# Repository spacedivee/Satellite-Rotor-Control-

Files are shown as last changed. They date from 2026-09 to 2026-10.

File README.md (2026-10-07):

iso all2

## *$FOR THE STARDANCE REVIEWERS$*
- In case you haven't read it through my comments already , my BOM.csv is irrelevant if you guys can **ship me a HackPad kit** +(the PCB grant). I need the exact same components as the components in the kit, so sending me my grant isn't necessary (Either way my BOM contains the same components bought individually (which just costs more than your bulk), so its a win-win for both of us if you ship a **HackPad kit**. Note: I would submit this project as a hackpad, but previous reviewers have been agaisnt that. Thank you for your understanding.

## Custom Satellite Control Interface
A custom PCB-based controller designed as a physical interface for controlling software on a computer. It can be used as a general-purpose control pad, with a focus on eventually controlling a **satellite antenna rotator** (which is another project I am building).

## Components and building materials.
* 4× MX-style buttons
* EC11E rotary encoder with push button
* 0.91" OLED display
* Seeed XIAO RP2040
* Custom KiCad PCB
* 3D-printed Onshape enclosure

## PCB+Circuit

pcb ctrl circuit1

## How It Works
The XIAO RP2040 reads the buttons and rotary encoder and sends their inputs to software running on a computer. The OLED provides feedback to the user. In my case, the OLED will display Azimuth and Elevation as they are being changed so the antenna adjustmenet can be simplified. The Encoder will be used to manually adjust the increment of the motors, such that each press will be greater or smaller, depending on the input. 
All of the information will then be sent to the XIAO, which will then sent it to my computer as keystroke data (my current method), which my antenna rotator software will then acknowledge. 

## Tools (if you were interested..?)

* **KiCad** — PCB design
* **Onshape** — enclosure design
* **Arduino/C++** — programming
* **JLCPCB** — PCB manufacturing

## Firmware
For the record, this is the only aspect of my project that was completely made by AI. The current firmware is a placeholder and I plan on writing it myself once I have built the board. I believe this is a better way
of doing things since I get to actively troubleshoot issues. I hope yall feel the same way about this ❤️.

## Bill of Materials

| Item | Component Name | Qty | Price (USD) | Notes |
| :---: | :--- | :---: | :---: | :--- |
| 1 | [Seeed XIAO RP2040](https://www.amazon.ca/dp/B0FB5BS2NX?psc=1&ref_=cm_sw_r_cp_ud_ct_R7M1Z3YGXBJXF9ZXZQDJ_10) | 1 | $19.32 | Main microcontroller |
| 2 | [1N4148 through-hole diodes](https://www.amazon.ca/dp/B099PPQ7YN?psc=1&ref_=cm_sw_r_cp_ud_ct_R7M1Z3YGXBJXF9ZXZQDJ_9) | 4 | $1.50 | Button/switch matrix |
| 3 | [MX-style switches](https://www.amazon.ca/dp/B0HJFQYWR2?psc=1&ref_=cm_sw_r_cp_ud_ct_R7M1Z3YGXBJXF9ZXZQDJ_8) | 4 | $5.99 | Main input buttons |
| 4 | [EC11E rotary encoder with switch](https://www.amazon.ca/dp/B0GJS5SQPF?psc=1&ref_=cm_sw_r_cp_ud_ct_R7M1Z3YGXBJXF9ZXZQDJ_7) | 1 | $8.79 | - |
| 5 | [0.91 inch OLED display](https://www.amazon.ca/dp/B0GWPY5LMY?psc=1&ref_=cm_sw_r_cp_ud_ct_R7M1Z3YGXBJXF9ZXZQDJ_5) | 1 | $6.67 | GND-VCC-SCL-SDA pin order |
| 6 | [White blank DSA keycaps](https://www.amazon.ca/dp/B0BWDR7LQQ?psc=1&ref_=cm_sw_r_cp_ud_ct_R7M1Z3YGXBJXF9ZXZQDJ_4) | 4 | $12.50 | Keycaps for MX switches |
| 7 | [M3x16mm screws](https://www.amazon.ca/dp/B0DDNJXLF3?psc=1&ref_=cm_sw_r_cp_ud_ct_R7M1Z3YGXBJXF9ZXZQDJ_3) | 4 | $8.59 | Case assembly |
| 8 | [M3x5mmx4mm heat-set inserts](https://www.amazon.ca/dp/B0BYVLPG4R?psc=1&ref_=cm_sw_r_cp_ud_ct_R7M1Z3YGXBJXF9ZXZQDJ_1) | 4 | $8.49 | Case assembly |
| 9 | $10 JLCPCB credit | 1 | $10.00 | PCB manufacturing |
| 10 | LED | 1 | $0.00 | - supplied by me |
| 11 | Resistor | 1 | $0.00 | - supplied by me |
| | **Total Estimated Cost:** | | **$81.85** | |

> **Note:** If you have an existing hackpad kit available, I would happily accept that as an alternative. It may be more cost-effective and prevents acquiring unnecessary duplicate components.

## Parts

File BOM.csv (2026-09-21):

Item Name | Qty | Price (total) (USD) | Item link | Notes
Seeed XIAO RP2040 | 1 | $19.32 | https://www.amazon.ca/dp/B0FB5BS2NX?psc=1&ref_=cm_sw_r_cp_ud_ct_R7M1Z3YGXBJXF9ZXZQDJ_10 | Main microcontroller
1N4148 through-hole diodes | 4 | $1.50 | https://www.amazon.ca/dp/B099PPQ7YN?psc=1&ref_=cm_sw_r_cp_ud_ct_R7M1Z3YGXBJXF9ZXZQDJ_9 | Button/switch matrix
MX-style switches | 4 | $5.99 | https://www.amazon.ca/dp/B0HJFQYWR2?psc=1&ref_=cm_sw_r_cp_ud_ct_R7M1Z3YGXBJXF9ZXZQDJ_8 | Main input buttons
EC11E rotary encoder with switch | 1 | $8.79 | https://www.amazon.ca/dp/B0GJS5SQPF?psc=1&ref_=cm_sw_r_cp_ud_ct_R7M1Z3YGXBJXF9ZXZQDJ_7 | -
0.91 inch OLED display | 1 | $6.67 | https://www.amazon.ca/dp/B0GWPY5LMY?psc=1&ref_=cm_sw_r_cp_ud_ct_R7M1Z3YGXBJXF9ZXZQDJ_5 | GND-VCC-SCL-SDA pin order
White blank DSA keycaps | 4 | $12.50 | https://www.amazon.ca/dp/B0BWDR7LQQ?psc=1&ref_=cm_sw_r_cp_ud_ct_R7M1Z3YGXBJXF9ZXZQDJ_4 | Keycaps for MX switches
M3x16mm screws | 4 | $8.59 | https://www.amazon.ca/dp/B0DDNJXLF3?psc=1&ref_=cm_sw_r_cp_ud_ct_R7M1Z3YGXBJXF9ZXZQDJ_3 | Case assembly
M3x5mmx4mm heat-set inserts | 4 | $8.49 | https://www.amazon.ca/dp/B0BYVLPG4R?psc=1&ref_=cm_sw_r_cp_ud_ct_R7M1Z3YGXBJXF9ZXZQDJ_1 | Case assembly
$10 JLCPCB credit | 1 | $10.00 |  | PCB manufacturing
LED | 1 | $0.00 |  | - supplied by me
Resistor | 1 | $0.00 |  | - supplied by me
Total Price (USD): | $81.85
However, if you guys have a hackpad kit laying around, i will gladly take that instead of all of this list of materials, since its cheaper for you and I dont require all of these extra parts for my project.

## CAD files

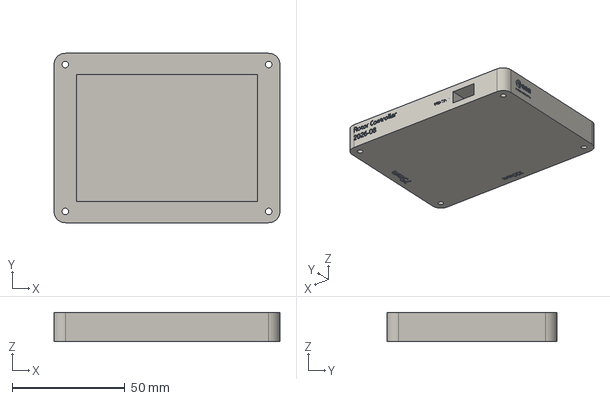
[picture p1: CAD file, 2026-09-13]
CaseFiles/Case(step).step
100.0 x 75.0 x 13.0 mm

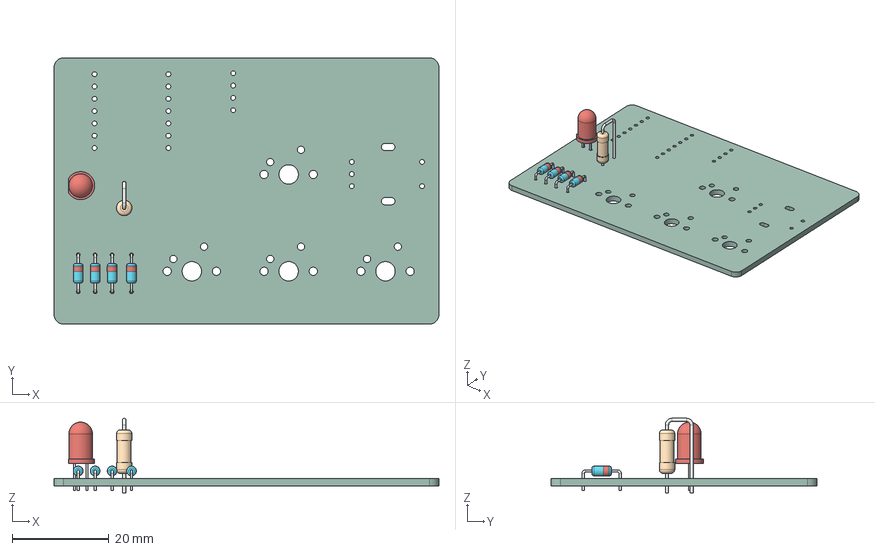
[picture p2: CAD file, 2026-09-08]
PCB/KiCad Files/yo/yo.step
79.5 x 55.0 x 15.4 mm
D_DO-35_SOD27_P7.62mm_Horizontal x 4
LED_D5.0mm
R_Axial_DIN0309_L90mm_D32mm_P508mm_Vertical
yo-37B0_PCB

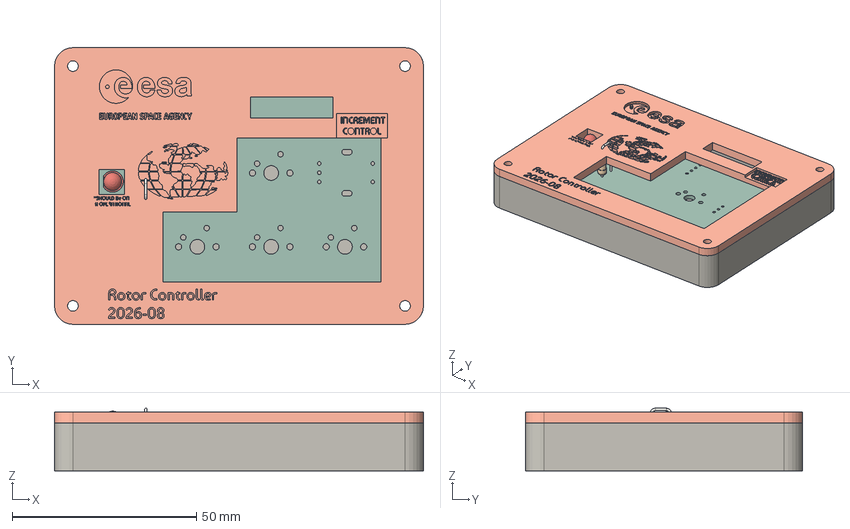
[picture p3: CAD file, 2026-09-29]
SatContrl_electronics+CAD.step
100.0 x 75.0 x 17.0 mm
main:1__Body5
main:1__Body16
main:1__Body4
main:1__Body10
main:1__Body13
main:1__Body6
main:1__Body12
main:1__Body1
main:1__Body9
smd_button v3:1__Body1
main:1__Body14
main:1__Body3
main:1__Body7
main:1__Body11
DOUT:1__Body1
VDD:1__Body1
VSS:1__Body1
DIN:1__Body1
Shell:1__Body1
main:1__Body15
main:1__Body8
type-c v2:1__Body2
type-c v2:1__Body6
type-c v2:1__Body4
type-c v2:1__Body20
type-c v2:1__Body5
type-c v2:1__Body15
type-c v2:1__Body17
type-c v2:1__Body3
type-c v2:1__Body11
type-c v2:1__Body1
type-c v2:1__Body23
type-c v2:1__Body7
type-c v2:1__Body12
type-c v2:1__Body14
type-c v2:1__Body13
type-c v2:1__Body16
type-c v2:1__Body21
type-c v2:1__Body8
type-c v2:1__Body22
type-c v2:1__Body18
type-c v2:1__Body24
type-c v2:1__Body9
type-c v2:1__Body19
type-c v2:1__Body10
smd_button v3(Mirror):1__Body2
main:1__Body17
R_Axial_DIN0309_L90mm_D32mm_P508mm_Vertical
D_DO-35_SOD27_P7.62mm_Horizontal x 8
LED_D5.0mm
yo-37B0_PCB

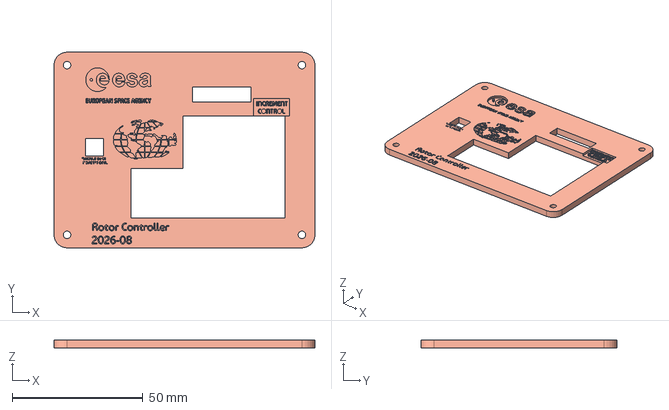
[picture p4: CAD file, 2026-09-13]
CaseFiles/Lid(step).step
100.0 x 75.0 x 3.00 mm

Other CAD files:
CaseFiles/CASELID.stl
CaseFiles/CASEBOTTOM.stl

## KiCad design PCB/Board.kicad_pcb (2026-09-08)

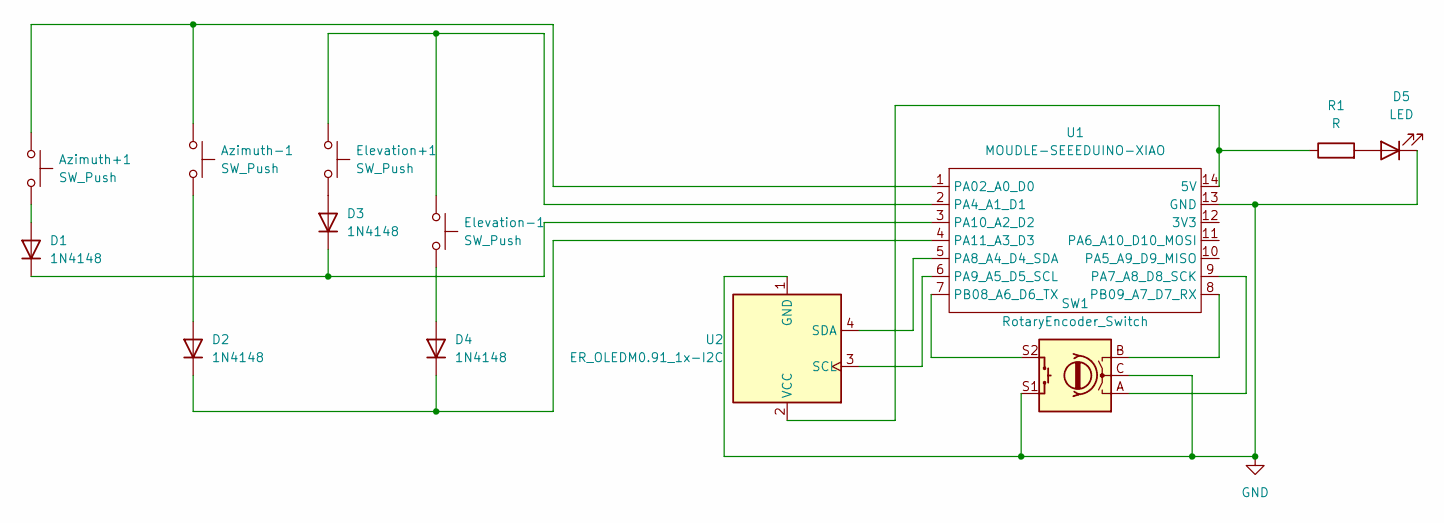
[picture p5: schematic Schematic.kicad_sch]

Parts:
Azimuth+1: SW_Push; SW_Cherry_MX_1.00u_PCB
Azimuth-1: SW_Push; SW_Cherry_MX_1.00u_PCB
D1, D2, D3, D4: 1N4148; D_DO-35_SOD27_P7.62mm_Horizontal
D5: LED; LED_D5.0mm
Elevation+1: SW_Push; SW_Cherry_MX_1.00u_PCB
Elevation-1: SW_Push; SW_Cherry_MX_1.00u_PCB
R1: R; R_Axial_DIN0309_L9.0mm_D3.2mm_P5.08mm_Vertical
SW1: RotaryEncoder_Switch; RotaryEncoder_Alps_EC11E-Switch_Vertical_H20mm
U1: MOUDLE-SEEEDUINO-XIAO; XIAO-Generic-Hybrid-14P-2.54-21X17.8MM
U2: ER_OLEDM0.91_1x-I2C; SSD1306-0.91-OLED-4pin-128x32

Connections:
GND: D5.1 (K), SW1.C, SW1.S1, U1.13 (GND), U2.1 (GND)
unnamed: Azimuth+1.2, D1.2 (A)
unnamed: D1.1 (K), D3.1 (K), U1.3 (PA10_A2_D2)
unnamed: Azimuth-1.2, D2.2 (A)
unnamed: D2.1 (K), D4.1 (K), U1.4 (PA11_A3_D3)
unnamed: D3.2 (A), Elevation+1.2
unnamed: D4.2 (A), Elevation-1.2
unnamed: D5.2 (A), R1.2
unnamed: R1.1, U1.14 (5V), U2.2 (VCC)
unnamed: Azimuth+1.1, Azimuth-1.1, U1.1 (PA02_A0_D0)
unnamed: Elevation+1.1, Elevation-1.1, U1.2 (PA4_A1_D1)
unnamed: SW1.A, U1.9 (PA7_A8_D8_SCK)
unnamed: U1.5 (PA8_A4_D4_SDA), U2.4 (SDA)
unnamed: U1.6 (PA9_A5_D5_SCL), U2.3 (SCL)
unnamed: SW1.S2, U1.7 (PB08_A6_D6_TX)
unnamed: SW1.B, U1.8 (PB09_A7_D7_RX)

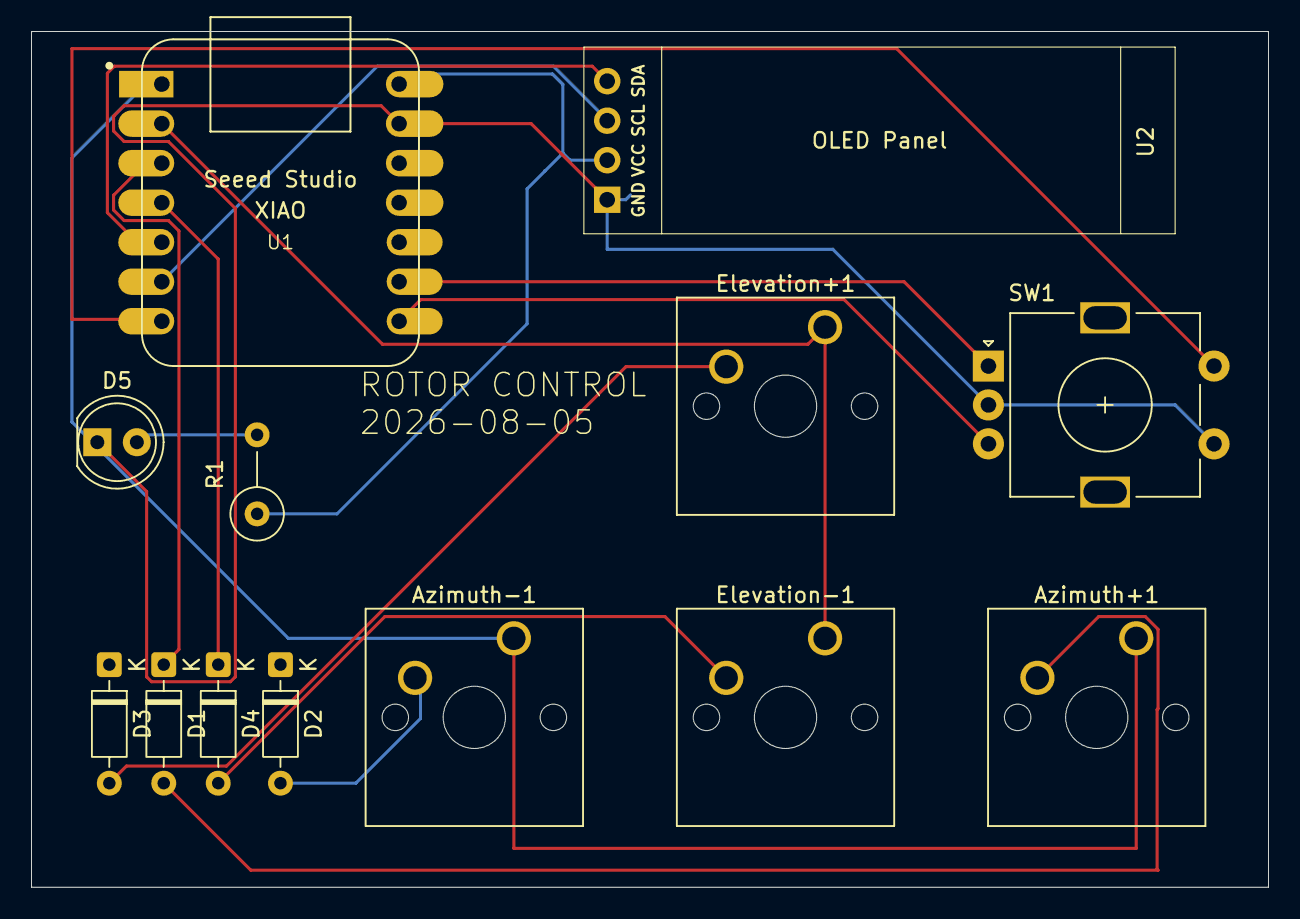
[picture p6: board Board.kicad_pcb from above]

Board: 2 copper layers, 79.5 x 55.0 mm, 13 parts (0 on the bottom side), 16 nets.

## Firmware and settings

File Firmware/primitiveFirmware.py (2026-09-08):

import time
import board
import busio
import digitalio
import rotaryio
import displayio
import terminalio
import usb_cdc
from adafruit_display_text import label
import adafruit_ssd1306

# --- 1. Initialize Status LED (Pin 14 / D11) ---
status_led = digitalio.DigitalInOut(board.D11)
status_led.direction = digitalio.Direction.OUTPUT
status_led.value = False

def flash_led():
    """Blinks the status LED quickly when a command is sent."""
    status_led.value = True
    time.sleep(0.05)
    status_led.value = False

# --- 2. Initialize 128x32 OLED Display (SDA=D9, SCL=D10) ---
displayio.release_displays()
i2c = busio.I2C(scl=board.D10, sda=board.D9)
display_bus = displayio.I2CDisplay(i2c, device_address=0x3C)
display = adafruit_ssd1306.SSD1306(display_bus, width=128, height=32)

# --- 3. Easy UI Formatting ---
splash = displayio.Group()
display.root_group = splash

title_text = label.Label(terminalio.FONT, text="TRACKER ACTIVE", x=2, y=6)
az_text = label.Label(terminalio.FONT, text="AZ: 180°", x=2, y=22)
el_text = label.Label(terminalio.FONT, text="EL: 00°", x=70, y=22)

splash.append(title_text)
splash.append(az_text)
splash.append(el_text)

def update_screen(az_val, el_val):
    az_text.text = f"AZ: {az_val:03d}°"
    el_text.text = f"EL: {el_val:02d}°"

# --- 4. Initialize 2x2 Button Matrix ---
# Rows (Outputs)
row_pins = [board.D0, board.D1]
rows = [digitalio.DigitalInOut(pin) for pin in row_pins]
for row in rows:
    row.direction = digitalio.Direction.OUTPUT
    row.value = True  # High by default

# Columns (Inputs)
col_pins = [board.D2, board.D3]
cols = [digitalio.DigitalInOut(pin) for pin in col_pins]
for col in cols:
    col.direction = digitalio.Direction.INPUT
    col.pull = digitalio.Pull.UP  # Pull-up required due to ground-facing matrix diodes

# Matrix state tracking memory to avoid repeated spamming
# Matrix map index: [0]=Azimuth+1, [1]=Elevation+1, [2]=Azimuth-1, [3]=Elevation-1
button_states = [True] * 4 

# --- 5. Initialize Rotary Encoder & Switch (A=D4, B=D5, SW=D6) ---
encoder = rotaryio.IncrementalEncoder(board.D4, board.D5)
last_encoder_position = encoder.position

enc_switch = digitalio.DigitalInOut(board.D6)
enc_switch.direction = digitalio.Direction.INPUT
enc_switch.pull = digitalio.Pull.UP
last_switch_state = True

# Live Variables
target_az = 180 
target_el = 0
control_mode = "AZ"  # Knob controls Azimuth first. Click to switch to Elevation.

def send_command(cmd_string):
    usb_cdc.console.write(f"{cmd_string}\n".encode('utf-8'))
    flash_led()

# Set starting baseline text
update_screen(target_az, target_el)

# --- 6. Main Control Loop ---
while True:
    # --- Matrix Scanning Routine ---
    current_matrix_clicks = [True] * 4
    
    # Scan Row 0 (Azimuth +1 and Elevation +1)
    rows[0].value = False  # Pull Row 0 Low
    current_matrix_clicks[0] = cols[0].value  # Read Col 0 (Azimuth +1)
    current_matrix_clicks[1] = cols[1].value  # Read Col 1 (Elevation +1)
    rows[0].value = True   # Reset Row 0 High

    # Scan Row 1 (Azimuth -1 and Elevation -1)
    rows[1].value = False  # Pull Row 1 Low
    current_matrix_clicks[2] = cols[0].value  # Read Col 0 (Azimuth -1)
    current_matrix_clicks[3] = cols[1].value  # Read Col 1 (Elevation -1)
    rows[1].value = True   # Reset Row 1 High

    # Process Matrix Click Actions (Trigger on Press Down / Fall to False)
    if not current_matrix_clicks[0] and button_states[0]:  # Azimuth +1 Button
        target_az = (target_az + 1) % 360
        send_command(f"GOTO AZ={target_az} EL={target_el}")
        update_screen(target_az, target_el)
        
    elif not current_matrix_clicks[2] and button_states[2]:  # Azimuth -1 Button
        target_az = (target_az - 1) % 360
        send_command(f"GOTO AZ={target_az} EL={target_el}")
        update_screen(target_az, target_el)
        
    elif not current_matrix_clicks[1] and button_states[1]:  # Elevation +1 Button
        target_el = max(0, min(90, target_el + 1))
        send_command(f"GOTO AZ={target_az} EL={target_el}")
        update_screen(target_az, target_el)
        
    elif not current_matrix_clicks[3] and button_states[3]:  # Elevation -1 Button
        target_el = max(0, min(90, target_el - 1))
        send_command(f"GOTO AZ={target_az} EL={target_el}")
        update_screen(target_az, target_el)

    # Save current matrix scan state for next loop iteration
    button_states = current_matrix_clicks

    # --- Rotary Encoder Scanning ---
    current_encoder_position = encoder.position
    if current_encoder_position != last_encoder_position:
        direction = 1 if current_encoder_position > last_encoder_position else -1
        
        # Dial Fine Tuning
        if control_mode == "AZ":
            target_az = (target_az + direction) % 360
        elif control_mode == "EL":
            target_el = max(0, min(90, target_el + direction))
        
        send_command(f"GOTO AZ={target_az} EL={target_el}")
        update_screen(target_az, target_el)
        last_encoder_position = current_encoder_position

    # --- Encoder Knob Click Toggle (Toggles Knob Focus) ---
    if not enc_switch.value and last_switch_state:
        if control_mode == "AZ":
            control_mode = "EL"
            title_text.text = "TUNE MODE: ELEV"
        else:
            control_mode = "AZ"
            title_text.text = "TUNE MODE: AZIM"
        time.sleep(0.15)  # Debounce delay
    last_switch_state = enc_switch.value

    time.sleep(0.01)  # General loop pacing

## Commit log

2026-09-08 Force upload all project folders and files
    [CASEBOTTOM.stl, CASELID.stl, Schematic.kicad_sch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]
2026-09-13 Update repository from local files
    [Board.kicad_pcb, Case(step).step, Lid(step).step]
2026-09-21 Add all new files
    [BOM.csv]
2026-09-28 Update images in README.md
    Updated image in README and added additional PCB image.
2026-09-29 Fix typos and update building materials section
    Corrected typos and improved clarity in the README.
2026-10-07 changed the URL for the read me BOM
2026-10-22 Rename CaseFiles to CAD and add final firmware files
